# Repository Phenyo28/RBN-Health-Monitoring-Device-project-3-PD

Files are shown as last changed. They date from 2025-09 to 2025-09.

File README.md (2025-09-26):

# 🩺RBN-Health-Monitoring-Device-project-3-PD
---
This project is an IoT-enabled healthcare monitoring device designed to measure and record vital signs, specifically pulse rate and body temperature, in real time. Using sensors connected to an ESP32 microcontroller, the system collects health data and transmits it over Wi-Fi to a mobile application, where it is displayed for easy monitoring. The device provides a portable and affordable solution for continuous health tracking, making it useful for patients, caregivers, and healthcare providers. By enabling timely detection of irregularities and supporting remote access, the project contributes to improved preventive healthcare and has potential for future expansion with additional sensors and advanced features.

## Who is project is designed for?
- Patients who need continuous monitoring of vital signs.
- Caregivers and family members responsible for health supervision.
- Healthcare providers who want remote access to patient data for timely interventions.
---

## Repository Contents
| File / Folder | Description |
| --- | --- |
| `Picture` |Folder of the project building images |
| `BOM - PulseWave .xlsx` | Bill of materials |
| `README.md` |Update README.md |
| `Schematic.png` | Circuit schematic (image version) |
| `RP-Diale-PulseWave.ino` | Arduino source code for running the soil detector |
|`PULSEWAVE PERFOMANCE FLOW` | Perfomance workflow of the project |

---
## Features

- Sends health data wirelessly via Wi-Fi
- Measures heart rate (BPM) in real time
- Tracks body temperature with digital sensors
-  Shows live readings directly on the device
- Enables remote access to health data through a mobile app and the device itself
- Designed for everyday use in healthcare or home settings
---

## Components Used
| Component Name | Purpose in Project | Quantity |
| --- | --- | --- |
| `ESP32` | Main microcontroller; collects sensor data & controls outputs | 1 |
| `9 V Battery` | Powers the system | 1 |
| `Pulse Sensor` | Measures the user’s heart rate | 1 |
| `IR Thermometer Sensor` | Measures body temperature | 1 |
| `Breadboard` | Measures body temperature | 1 |
| `USB A-Male to Micro USB Male` | Powers or programs the ESP32 via USB | 1 |
| `LCD Screen` | Displays real-time sensor readings | 1 |
| `On/Off Switch` | Turns the device on or off | 1 |

---

## Software Development
-Arduino IDE (with ESP32 board support)

-Libraries:
- WiFi.h
- HTTPClient.h
- PulseSensorPlayground.h
- DFRobot_MLX90614.h
- Wire.h
- LiquidCrystal_I2C.h


## The Code

## How the Code Works

1. Initialization (setup)
- Connects to Wi-Fi
- Initializes Pulse Sensor, Temperature Sensor, and LCD display
- Starts a web server on the ESP32


2. Loop Operations (continuous monitoring)
- Reads pulse sensor raw values and detects heartbeats
- Calculates BPM (Beats Per Minute)
- Reads object temperature (body) and ambient temperature
- Prints results to the Serial Monitor for debugging
- Updates the LCD with current BPM & body temperature
- Sends data every 15 seconds to ThingSpeak (API call via HTTP)
- Hosts a web dashboard showing real-time BPM, temperature, signal strength, and health state


3. Health Logic & Thresholds
- Pulse thresholds:
- `< 60 BPM` → Low (bradycardia risk)
- `60–100 BPM` → Normal
- `> 100 BPM` → High (tachycardia risk)
- Temperature thresholds:
- `< 36°C` → Low (hypothermia risk)
- `36–37.5°C` → Normal
- `> 37.5°C` → High (fever/infection risk)
- The system explains the possible causes of abnormal readings (e.g., stress, infection, dehydration).


4. Web Dashboard
- Auto-refreshes every 2 seconds
- Displays:
- Heartbeat animation ♥ when pulse is detected
- BPM, temperature, and signal strength
- Current health state messages (normal, high, low)
- ThingSpeak connection status & next update timer


## Perfomance workflow of the project


---

## Schematic Design. 
I created  the schematic design of this project using draw.io. I started by mapping out all the components, including the ESP32 microcontroller, pulse sensor, temperature sensor, switch, LCD, and a 9v battery, then arranged them to make connections. This schematic helped plan the physical wiring, guided the coding process, and ensured that the system could reliably collect and transmit data.



## App Development
I used the MIT App inventor to create my app. The pulse rate and body temperature readings from the ESP32 are displayed on the LCD screen of the device and in the mobile app for real-time monitoring. The same data is also sent to ThingSpeak, where it is visualized in real-time graphs, allowing users to track trends over time and monitor their health data effectively both locally and via the cloud.


- 	The first screen is the home screen
- 	Second screen is about how the app works and the benefits of using the app
- 	The third and fourth screens show the temperature and pulse readings.
- 	I added buttons so the user can navigate between the screens on the app. I used block code logic to handle the transitions

---

## How the ThingSpeak Readings Work
The ESP32 collects pulse and temperature values from the sensors and connects to Wi-Fi. These readings are then sent to ThingSpeak, an IoT analytics platform, using its API. Each data value is uploaded to a specific channel field (for example, Field 1 = Pulse Rate, Field 2 = Signal Strength, Field 3 = Object Temperature, Field 4 = Ambient Temperature). ThingSpeak stores the data in the cloud and displays it in real-time through interactive graphs and charts. This allows continuous monitoring of trends over time, remote access to health data, and easy integration with data analysis or alert systems.


---
## The Casing
I created the casing on OnShape. This casing will provide protection for the electronics, gave it a cleaner look, and made the device portable.




---
## Process of working on the Project

## Soldering:
IMG-20250901-WA0003

---
## Component Testing:
---
IMG-20250905-WA0006 IMG-20250905-WA0009
---

## Challenges I faced when building this project
During this project, I faced several challenges. The LCD screen was not working properly, it would turn on and off (and not work for a long time). Some components were overheating and some would not work when I connected them to my breadboard. The serial monitor failed to recognize certain components sometimes, to solve this I used an I2C scanner to correctly identify and connect the devices, which helped stabilize the system. The readings of my components were displaying slow. My ESP32 microcontroller burnt and was not responsive, this delayed the process as I had to source a replacement device before I could continue testing and integrating the components.

---

## Conclusion

This project gave me hands-on experience with IoT, embedded systems, and hardware designs. I learnt how to integrate multiple sensors with the ESP32, and create a web dashboard for real-time health monitoring. Despite challenges like overheating components and hardware failures, I gained valuable troubleshooting skills and a deeper understanding of electronics and prototyping.

## Acknowledgements

Special thanks to my workshop instructors, my peers (especially Lesane for helping me troubleshoot), and the online community resources that guided me throughout this journey.

## Future Improvements

In the future, I plan to:
- Improve the stability of the ESP32 setup and explore better power management.
- Add more sensors to expand health monitoring features.
- Develop a more user-friendly mobile app for live tracking.
- Explore 3D printing for more compact and durable casings.

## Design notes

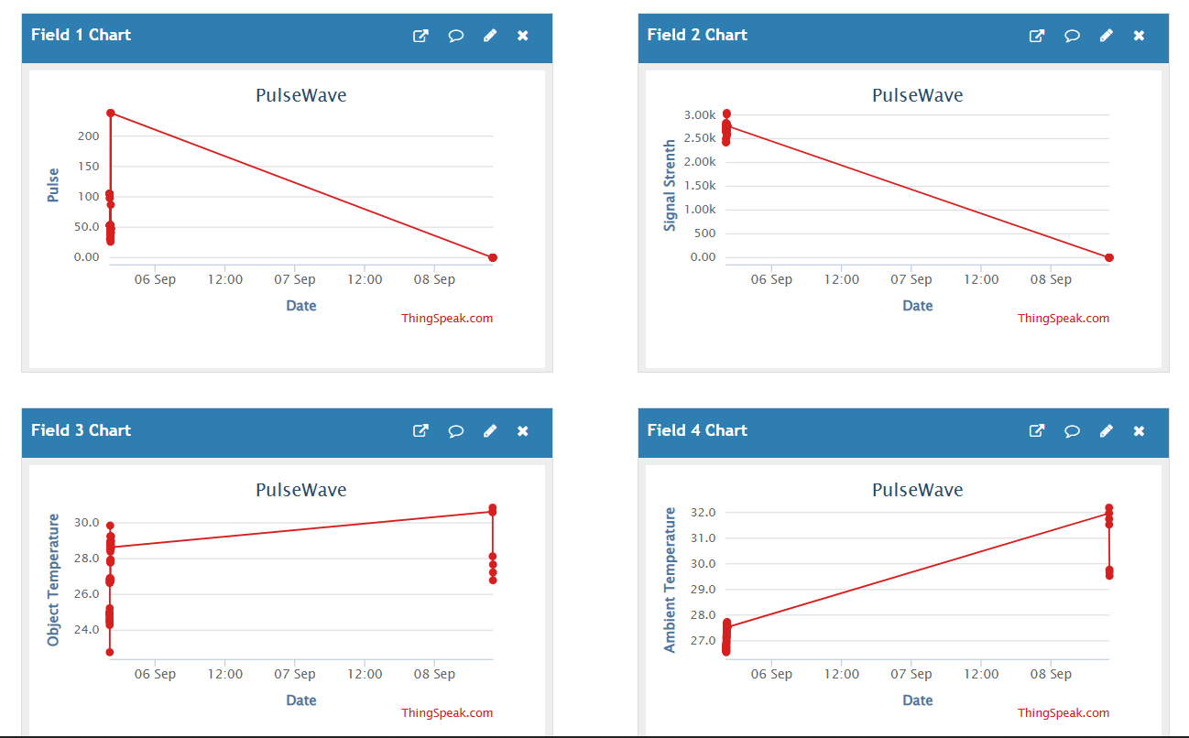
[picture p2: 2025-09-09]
Picture/ThingSpeak.png

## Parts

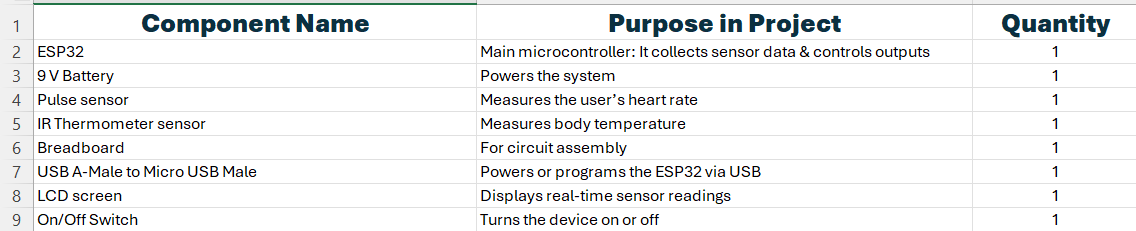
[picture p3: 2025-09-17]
BOM.png

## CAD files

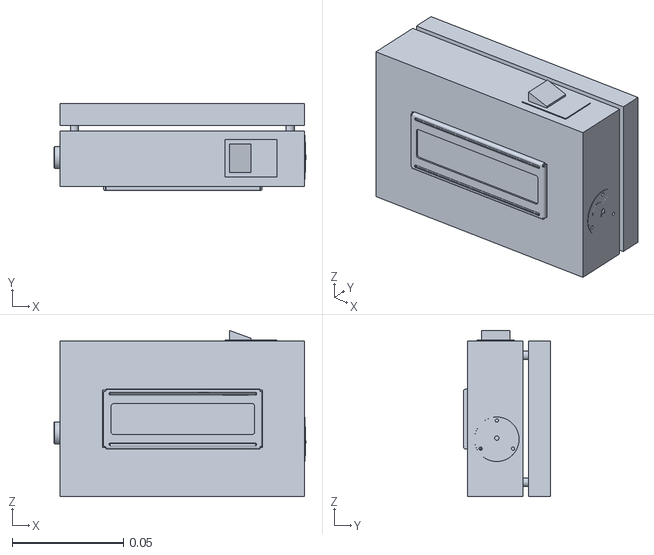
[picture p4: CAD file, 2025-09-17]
Assembly/Assembly 1.stl
0.113 x 0.0393 x 0.0747

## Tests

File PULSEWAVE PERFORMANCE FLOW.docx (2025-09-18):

PULSEWAVE PERFORMANCE FLOW

Power On
The ESP32 is powered by the 9V battery.
Data Collection
Pulse sensor measures BPM
IR thermometer measures body temperature.
Processing
ESP32 reads data and processes it
Output Options:
Serial Output - Data sent to Arduino IDE/serial monitor for debugging.
LCD Display - (intended, but currently not working) shows real-time readings locally.
ThingSpeak Upload - ESP32 sends data to the ThingSpeak cloud for storage and visualization.
Web Dashboard - ESP32 hosts a live web page that displays BPM and temperature.
App Access
MIT App Inventor app fetches data from ThingSpeak and displays it on a smartphone.
User Monitoring
Patients, caregivers or healthcare providers can monitor vitalls in real time through the app, ThingSpeak graphs, or web dashboard

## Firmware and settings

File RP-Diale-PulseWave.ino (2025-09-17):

#include <WiFi.h>
#include <HTTPClient.h>
#include <PulseSensorPlayground.h>
#include <DFRobot_MLX90614.h>
#include <Wire.h>
#include <LiquidCrystal_I2C.h>

// WiFi credentials
const char* ssid = "VodafoneMobileWiFi-CECE77";
const char* password = "4830970720";

// ThingSpeak settings
const char* thingSpeakApiKey = "QM6FSNLXACU35YQE";
const unsigned long thingSpeakPostDelay = 15000; // 15 sec
unsigned long lastThingSpeakPost = 0;

// Pulse Sensor Setup
const int PulseWire = 34;       // PulseSensor connected to pin 34
int Threshold = 2000;           // Threshold for detection

PulseSensorPlayground pulseSensor;
DFRobot_MLX90614_I2C mlxSensor;

// LCD Setup 
LiquidCrystal_I2C lcd(0x27, 16, 2);

// Web server
WiFiServer server(80);

// Variables
int myBPM = 0;
unsigned long lastBeatTime = 0;
bool beatDetected = false;
int signalStrength = 0;
float ambientTemp = 0;
float objectTemp = 0;
int rawPulseValue = 0;

// Timers
unsigned long lastTempRead = 0;
unsigned long lastDisplay = 0;
unsigned long lastLCD = 0;

//  HEALTH STATE FUNCTIONS
String getPulseState(int bpm) {
  if (bpm < 60) {
    return "Low Pulse (Bradycardia) - Possible causes: fatigue, heart issues, or medications.";
  } else if (bpm > 100) {
    return "High Pulse (Tachycardia) - Possible causes: exercise, stress, fever, or dehydration.";
  } else {
    return "Normal Pulse - Body is fine.";
  }
}

String getTempState(float temp) {
  if (temp < 36.0) {
    return "Low Temperature (Hypothermia risk) - Possible causes: cold exposure or circulation issues.";
  } else if (temp > 37.5) {
    return "High Temperature (Fever) - Possible causes: infection, overheating, or inflammation.";
  } else {
    return "Normal Temperature - Body is fine.";
  }
}

// SETUP
void setup() {
  Serial.begin(115200);
  Serial.println("Initializing ESP32 Health Monitor...");

  // Init I2C + LCD
  Wire.begin();
  lcd.init();
  lcd.backlight();
  lcd.setCursor(0, 0);
  lcd.print("IoT Health Monitor");
  lcd.setCursor(0, 1);
  lcd.print("Starting...");

  // Configure Pulse Sensor
  pulseSensor.analogInput(PulseWire);
  pulseSensor.setThreshold(Threshold);
  pulseSensor.setSerial(Serial);

  if (pulseSensor.begin()) {
    Serial.println("PulseSensor initialized!");
  } else {
    Serial.println("PulseSensor failed!");
  }

  // Init MLX90614 Temp Sensor
  if (NO_ERR != mlxSensor.begin()) {
    Serial.println("MLX90614 failed, check wiring.");
  } else {
    Serial.println("MLX90614 initialized!");
  }

  // Wi-Fi connect
  connectToWiFi();

  // Start web server
  server.begin();
  Serial.println("Web server started");
  lcd.clear();
}

// MAIN LOOP
void loop() {
  unsigned long currentMillis = millis();

  // Reconnect WiFi if dropped
  if (WiFi.status() != WL_CONNECTED) {
    connectToWiFi();
  }

  // Read raw pulse
  rawPulseValue = analogRead(PulseWire);
  signalStrength = rawPulseValue;

  if (pulseSensor.sawStartOfBeat()) {
    myBPM = pulseSensor.getBeatsPerMinute();
    lastBeatTime = currentMillis;
    beatDetected = true;
    Serial.println("♥ HeartBeat detected!");
  }

  // Read temperature every 1 sec
  if (currentMillis - lastTempRead >= 1000) {
    ambientTemp = mlxSensor.getAmbientTempCelsius();
    objectTemp = mlxSensor.getObjectTempCelsius();
    lastTempRead = currentMillis;
  }

  // Print to Serial every 1 sec
  if (currentMillis - lastDisplay >= 1000) {
    Serial.println("SENSOR READINGS");
    Serial.print("BPM: "); Serial.println(myBPM);
    Serial.print("Signal: "); Serial.println(signalStrength);
    Serial.print("Object Temp: "); Serial.print(objectTemp); Serial.println("°C");
    Serial.print("Ambient Temp: "); Serial.print(ambientTemp); Serial.println("°C");
    Serial.println("Pulse Status: " + getPulseState(myBPM));
    Serial.println("Temperature Status: " + getTempState(objectTemp));
    lastDisplay = currentMillis;
  }

  // Update LCD every 1 sec
  if (currentMillis - lastLCD >= 1000) {
    lcd.clear();
    lcd.setCursor(0, 0);
    if (beatDetected && (currentMillis - lastBeatTime < 5000)) {
      lcd.print("Pulse: " + String(myBPM) + " bpm");
    } else {
      lcd.print("Pulse: ---");
    }
    lcd.setCursor(0, 1);
    lcd.print("Temp: " + String(objectTemp, 1) + " C");
    lastLCD = currentMillis;
  }

  // Send to ThingSpeak every 15 sec
  if (currentMillis - lastThingSpeakPost > thingSpeakPostDelay) {
    if (WiFi.status() == WL_CONNECTED) {
      sendToThingSpeak();
    }
    lastThingSpeakPost = currentMillis;
  }

  // Web client
  WiFiClient client = server.available();
  if (client) {
    handleClientRequest(client);
  }
}

// FUNCTIONS
void connectToWiFi() {
  Serial.print("Connecting to ");
  Serial.println(ssid);
  WiFi.begin(ssid, password);
  int attempts = 0;
  while (WiFi.status() != WL_CONNECTED && attempts < 20) {
    delay(500);
    Serial.print(".");
    attempts++;
  }
  if (WiFi.status() == WL_CONNECTED) {
    Serial.println("\nWiFi connected, IP: " + WiFi.localIP().toString());
  } else {
    Serial.println("\nWiFi connect failed.");
  }
}

void sendToThingSpeak() {
  HTTPClient http;
  String url = "http://api.thingspeak.com/update?api_key=" + String(thingSpeakApiKey) +
               "&field1=" + String(myBPM) +
               "&field2=" + String(signalStrength) +
               "&field3=" + String(objectTemp) +
               "&field4=" + String(ambientTemp);
  http.begin(url);
  int httpCode = http.GET();
  if (httpCode > 0) {
    Serial.println("Data sent to ThingSpeak.");
  } else {
    Serial.println("ThingSpeak send failed.");
  }
  http.end();
}

// WEB DASHBOARD
void handleClientRequest(WiFiClient client) {
  String currentLine = "";
  unsigned long timeout = millis() + 250;

  while (client.connected() && millis() < timeout) {
    if (client.available()) {
      char c = client.read();
      if (c == '\n') {
        if (currentLine.length() == 0) {
          // Send HTTP response
          client.println("HTTP/1.1 200 OK");
          client.println("Content-type:text/html");
          client.println("Connection: close");
          client.println();

          // Web page content
          client.println("<!DOCTYPE html><html>");
          client.println("<head><meta name=\"viewport\" content=\"width=device-width, initial-scale=1\">");
          client.println("<meta http-equiv=\"refresh\" content=\"2\">"); // faster refresh
          client.println("<link rel=\"icon\" href=\"data:,\">");
          client.println("<style>");
          client.println("body { text-align: center; font-family: Arial, sans-serif; background: linear-gradient(to bottom, #1a1a2e, #16213e); color: white; margin: 0; padding: 20px; }");
          client.println(".container { max-width: 600px; margin: 0 auto; background: rgba(255, 255, 255, 0.1); border-radius: 15px; padding: 20px; box-shadow: 0 4px 6px rgba(0, 0, 0, 0.1); }");
          client.println(".heart { color: #e94560; font-size: 3em; animation: pulse 1.5s infinite; }");
          client.println("@keyframes pulse { 0% { transform: scale(1); } 50% { transform: scale(1.1); } 100% { transform: scale(1); } }");
          client.println(".data { font-size: 1.8em; margin: 20px; padding: 15px; background: rgba(255, 255, 255, 0.15); border-radius: 10px; }");
          client.println(".temp-data { font-size: 1.4em; margin: 15px; padding: 10px; background: rgba(255, 255, 255, 0.1); border-radius: 8px; }");
          client.println(".signal { height: 20px; background: #4cc9f0; border-radius: 10px; margin: 10px 0; }");
          client.println("h1 { color: #4cc9f0; }");
          client.println(".status { margin-top: 20px; font-size: 0.9em; color: #a5b1c2; }");
          client.println("</style></head>");
          client.println("<body><div class='container'>");
          client.println("<h1>ESP32 Health Monitor</h1>");

          if (beatDetected && (millis() - lastBeatTime < 5000)) {
            client.println("<div class=\"heart\">♥</div>");
            client.println("<div class=\"data\">BPM: " + String(myBPM) + "</div>");
            client.println("<div>Signal Strength: " + String(signalStrength) + "</div>");
            client.println("<div class=\"signal\" style=\"width: " + String(map(signalStrength, 0, 4095, 0, 100)) + "%;\"></div>");
            client.println("<div>Last beat: " + String((millis() - lastBeatTime)/1000) + " seconds ago</div>");
          } else {
            client.println("<div class=\"data\">Place your finger on the sensor</div>");
            client.println("<div>Signal Strength: " + String(signalStrength) + "</div>");
            client.println("<div class=\"signal\" style=\"width: " + String(map(signalStrength, 0, 4095, 0, 100)) + "%;\"></div>");
            beatDetected = false;
          }

          // Temperature data
          client.println("<div class=\"temp-data\">");
          client.println("Object Temperature: " + String(objectTemp, 1) + "°C<br>");
          client.println("Ambient Temperature: " + String(ambientTemp, 1) + "°C");
          client.println("</div>");

          // Show health states
          client.println("<div class=\"status\">");
          client.println("Pulse Status: " + getPulseState(myBPM) + "<br>");
          client.println("Temperature Status: " + getTempState(objectTemp));
          client.println("</div>");

          // WiFi & ThingSpeak
          client.println("<div class=\"status\">");
          client.println("ThingSpeak: " + String((WiFi.status() == WL_CONNECTED) ? "Connected" : "Disconnected"));
          client.println("<br>Next update in: " + String((thingSpeakPostDelay - (millis() - lastThingSpeakPost)) / 1000) + "s");
          client.println("</div>");

          client.println("</div></body></html>");
          break;
        } else {
          currentLine = "";
        }
      } else if (c != '\r') {
        currentLine += c;
      }
    }
  }
  client.stop();
}

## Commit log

2025-09-09 Pictures/ Circuit Diagram
2025-09-09 Rename Screenshot 2025-09-06 192206.png to Picture/ Circuit Diagram_Screenshot 2025-09-06 192206.png
2025-09-17 Arduino IDE Code
2025-09-17 Bill of materials
    [BOM - PulseWave .xlsx]
2025-09-17 STL Steps file
    [Assembly 1.stl]
2025-09-17 Update Assembly 1.step
    Steps file
2025-09-17 Updated folder for 3D files
    [Assembly 1.step]
2025-09-17 Bill of materials.png
